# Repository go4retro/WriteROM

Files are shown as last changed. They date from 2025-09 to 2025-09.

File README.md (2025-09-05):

# WriteROM

WriteROM accomplishes the impossible, allowing one to write a ROM in place while installed in a circuit without a write line. No flying leads or pigtails are required. WriteROM allows writing to the FLASH using only read accesses.

In normal operation, WriteROM works just like a normal 28 pin JEDEC ROM. However, once a "knock" sequence of reads are performed on the device, the device enters into a programming mode, where address bits 7-0 are interpreted as the data, and bits 11-8 are considered the "operation". The following operations are supported:

| 10:8 | Description |
| ---- | --- |
| 0 | set low byte of address |
| 1 | set middle byte of address |
| 2 | set high byte of address |
| 6 | read from stored address |
| 7 | write to address |

As expected, programming times will be increased due to the additional level of abstraction, but such a device can be cleanly inserted into any memory map, even those not allowing writes to a specific range of memory.

Currently, the design includes a 4Mbit (512kB) FLASH ROM, though the design can be extended to larger sizes if desired.

## License

Copyright (C) 2025 RETRO Innovations

These files are free designs; you can redistribute them and/or modify
them under the terms of the Creative Commons Attribution-ShareAlike 
4.0 International License.

You should have received a copy of the license along with this
work. If not, see http://creativecommons.org/licenses/by-sa/4.0/.

These files are distributed in the hope that they will be useful,
but WITHOUT ANY WARRANTY; without even the implied warranty of
MERCHANTABILITY or FITNESS FOR A PARTICULAR PURPOSE. See the
license for more details.

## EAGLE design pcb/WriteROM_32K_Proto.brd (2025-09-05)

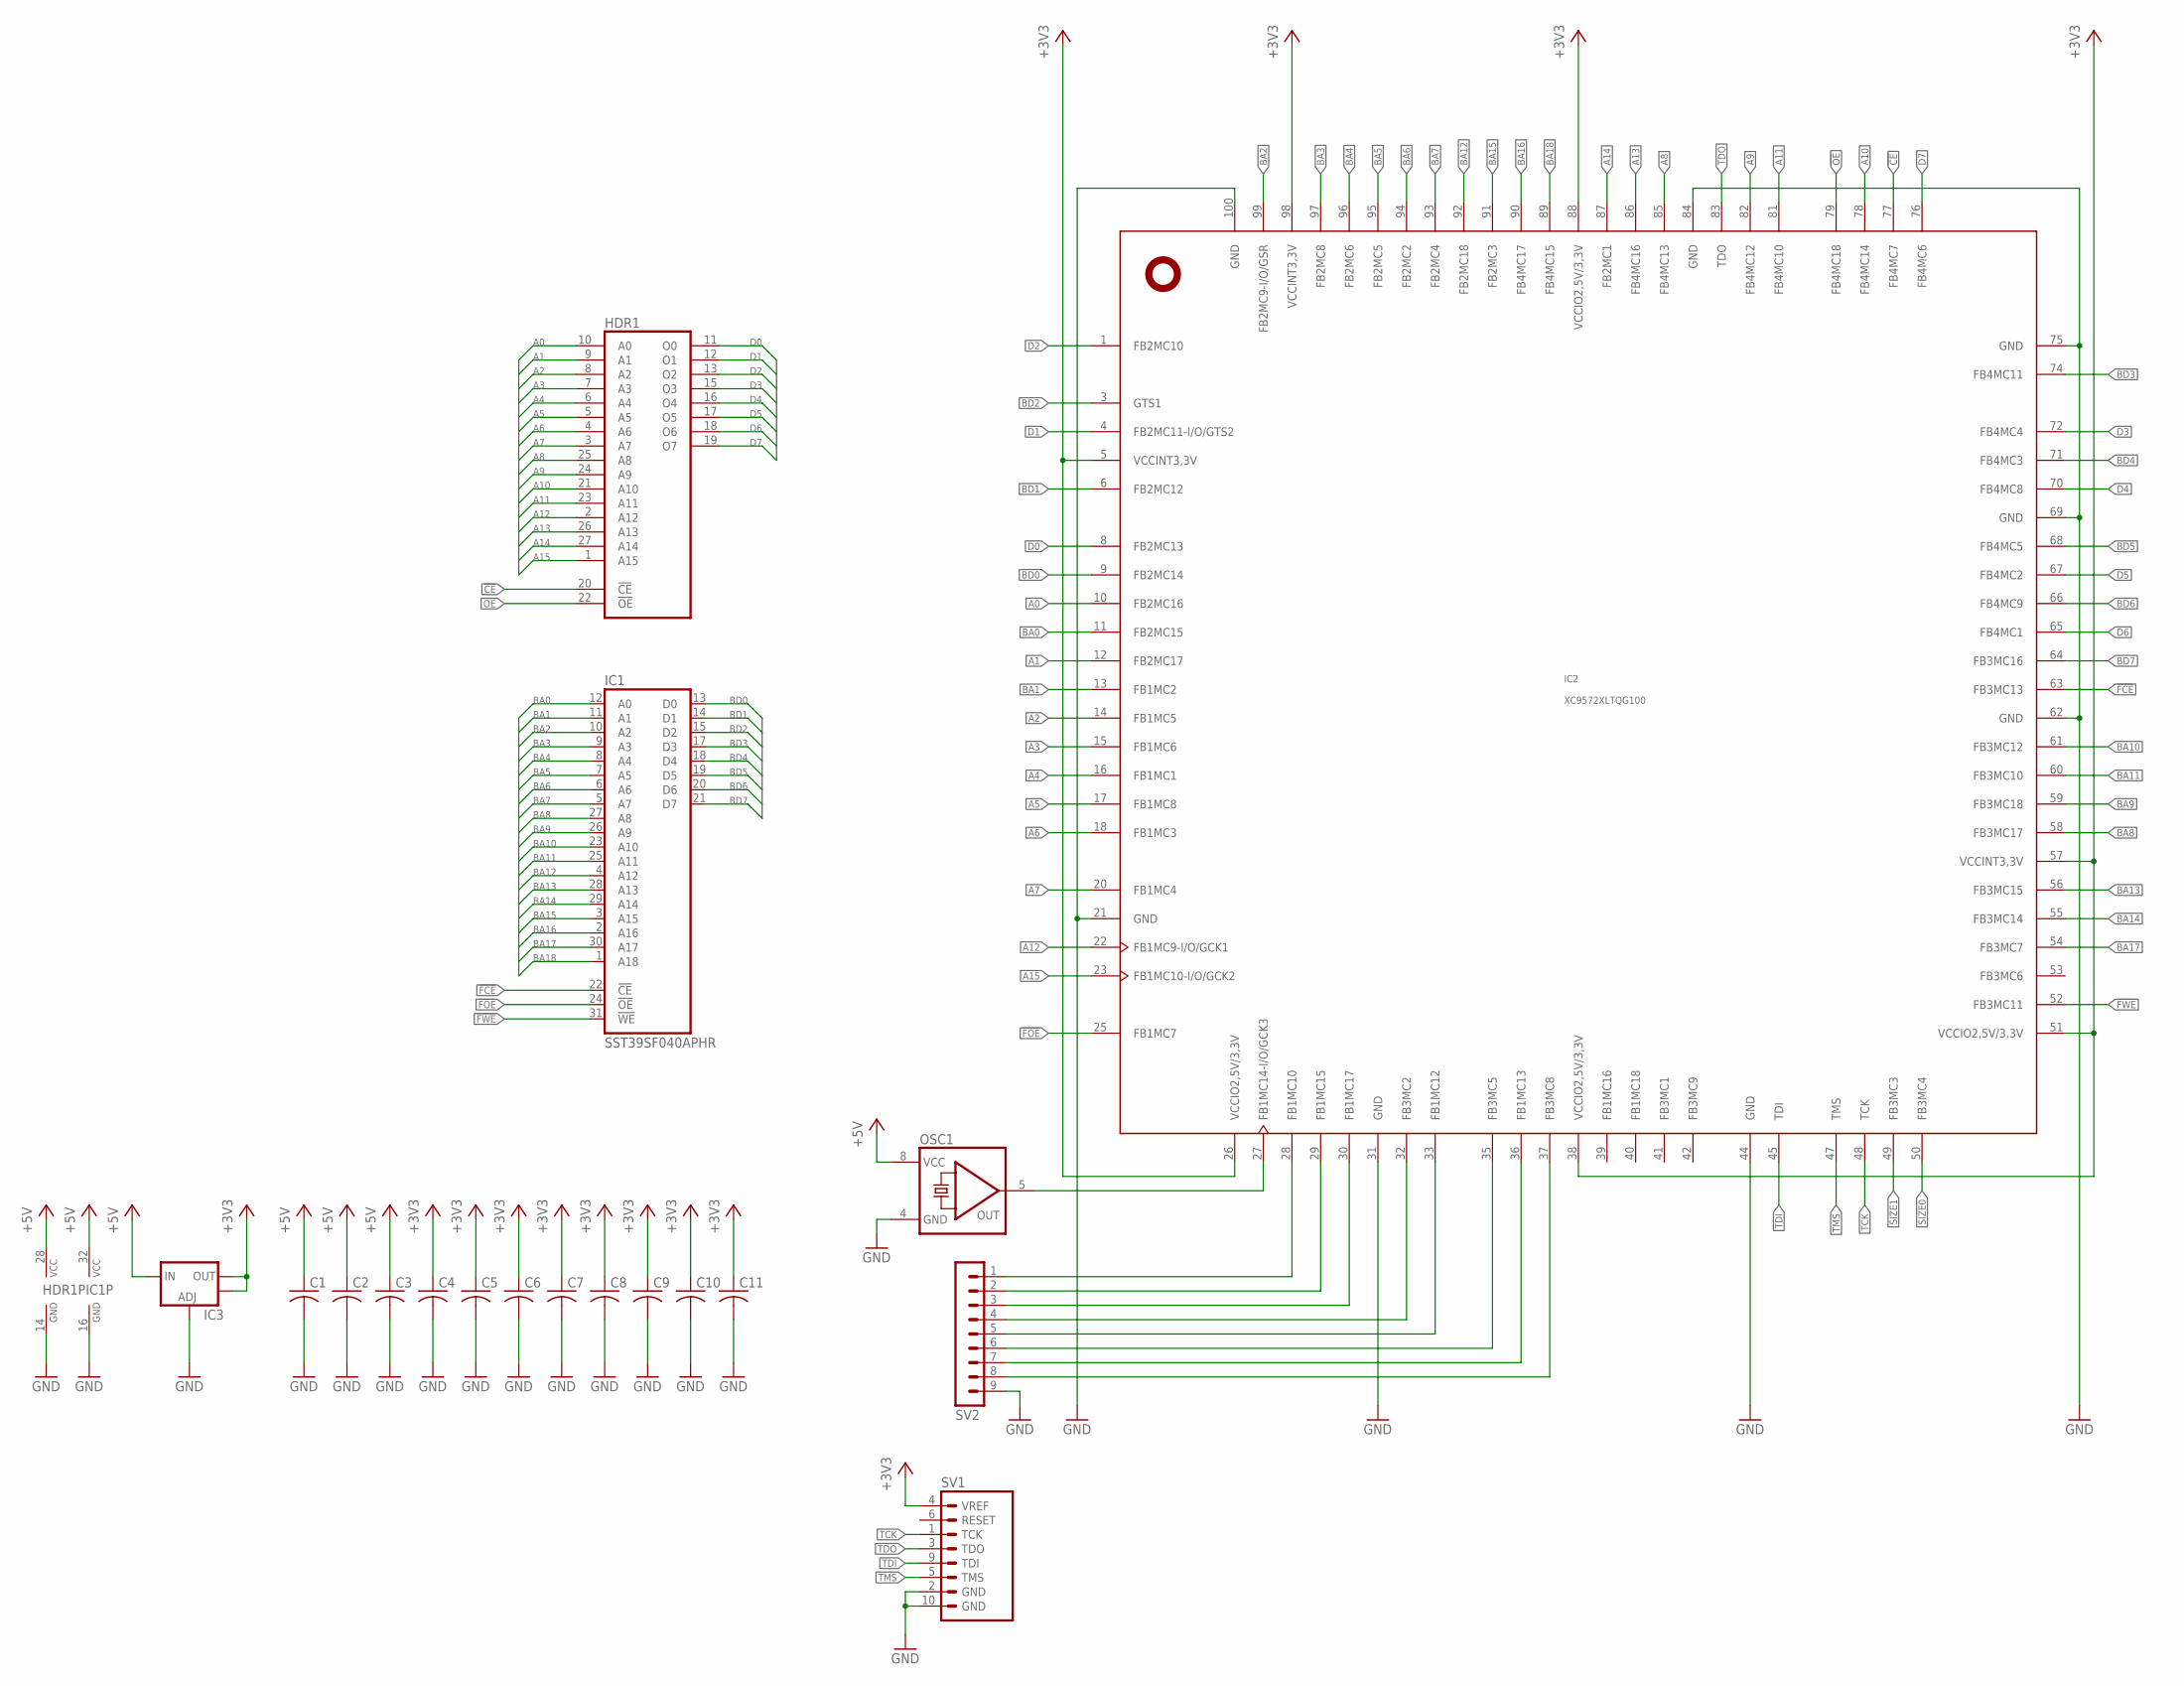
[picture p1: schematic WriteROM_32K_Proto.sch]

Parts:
C1, C4: C-USC0805; C0805
C2, C3, C5, C6, C7, C8, C9, C10, C11: C-USC0402; C0402
HDR1: 27512; DIL28
IC1: SST39SF040APHR; DIL32-RP
IC2: XC9572XLTQG100; TQFP100
IC3: V_REG_LM1117SOT223; SOT223
OSC1: QG5460; DIL08S
SV1: JTAG
SV2: MA09-1

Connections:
!CE: HDR1.20 (!CE), IC2.77 (FB4MC7)
!FCE: IC1.22 (!CE), IC2.63 (FB3MC13)
!FOE: IC1.24 (!OE), IC2.25 (FB1MC7)
!FWE: IC1.31 (!WE), IC2.52 (FB3MC11)
!OE: HDR1.22 (!OE), IC2.79 (FB4MC18)
+3V3: C4.1, C5.1, C6.1, C7.1, C8.1, C9.1, C10.1, C11.1, IC2.5 (VCCINT3,3V), IC2.26 (VCCIO2,5V/3,3V), IC2.38 (VCCIO2,5V/3,3V), IC2.51 (VCCIO2,5V/3,3V), IC2.57 (VCCINT3,3V), IC2.88 (VCCIO2,5V/3,3V), IC2.98 (VCCINT3,3V), IC3.2 (OUT), IC3.4 (OUT), SV1.4 (VREF)
+5V: C1.1, C2.1, C3.1, HDR1.28 (VCC), IC1.32 (VCC), IC3.3 (IN), OSC1.8 (VCC)
A0: HDR1.10 (A0), IC2.10 (FB2MC16)
A1: HDR1.9 (A1), IC2.12 (FB2MC17)
A2: HDR1.8 (A2), IC2.14 (FB1MC5)
A3: HDR1.7 (A3), IC2.15 (FB1MC6)
A4: HDR1.6 (A4), IC2.16 (FB1MC1)
A5: HDR1.5 (A5), IC2.17 (FB1MC8)
A6: HDR1.4 (A6), IC2.18 (FB1MC3)
A7: HDR1.3 (A7), IC2.20 (FB1MC4)
A8: HDR1.25 (A8), IC2.85 (FB4MC13)
A9: HDR1.24 (A9), IC2.82 (FB4MC12)
A10: HDR1.21 (A10), IC2.78 (FB4MC14)
A11: HDR1.23 (A11), IC2.81 (FB4MC10)
A12: HDR1.2 (A12), IC2.22 (FB1MC9-I/O/GCK1)
A13: HDR1.26 (A13), IC2.86 (FB4MC16)
A14: HDR1.27 (A14), IC2.87 (FB2MC1)
A15: HDR1.1 (A15), IC2.23 (FB1MC10-I/O/GCK2)
BA0: IC1.12 (A0), IC2.11 (FB2MC15)
BA1: IC1.11 (A1), IC2.13 (FB1MC2)
BA2: IC1.10 (A2), IC2.99 (FB2MC9-I/O/GSR)
BA3: IC1.9 (A3), IC2.97 (FB2MC8)
BA4: IC1.8 (A4), IC2.96 (FB2MC6)
BA5: IC1.7 (A5), IC2.95 (FB2MC5)
BA6: IC1.6 (A6), IC2.94 (FB2MC2)
BA7: IC1.5 (A7), IC2.93 (FB2MC4)
BA8: IC1.27 (A8), IC2.58 (FB3MC17)
BA9: IC1.26 (A9), IC2.59 (FB3MC18)
BA10: IC1.23 (A10), IC2.61 (FB3MC12)
BA11: IC1.25 (A11), IC2.60 (FB3MC10)
BA12: IC1.4 (A12), IC2.92 (FB2MC18)
BA13: IC1.28 (A13), IC2.56 (FB3MC15)
BA14: IC1.29 (A14), IC2.55 (FB3MC14)
BA15: IC1.3 (A15), IC2.91 (FB2MC3)
BA16: IC1.2 (A16), IC2.90 (FB4MC17)
BA17: IC1.30 (A17), IC2.54 (FB3MC7)
BA18: IC1.1 (A18), IC2.89 (FB4MC15)
BD0: IC1.13 (D0), IC2.9 (FB2MC14)
BD1: IC1.14 (D1), IC2.6 (FB2MC12)
BD2: IC1.15 (D2), IC2.3 (GTS1)
BD3: IC1.17 (D3), IC2.74 (FB4MC11)
BD4: IC1.18 (D4), IC2.71 (FB4MC3)
BD5: IC1.19 (D5), IC2.68 (FB4MC5)
BD6: IC1.20 (D6), IC2.66 (FB4MC9)
BD7: IC1.21 (D7), IC2.64 (FB3MC16)
D0: HDR1.11 (O0), IC2.8 (FB2MC13)
D1: HDR1.12 (O1), IC2.4 (FB2MC11-I/O/GTS2)
D2: HDR1.13 (O2), IC2.1 (FB2MC10)
D3: HDR1.15 (O3), IC2.72 (FB4MC4)
D4: HDR1.16 (O4), IC2.70 (FB4MC8)
D5: HDR1.17 (O5), IC2.67 (FB4MC2)
D6: HDR1.18 (O6), IC2.65 (FB4MC1)
D7: HDR1.19 (O7), IC2.76 (FB4MC6)
GND: C1.2, C2.2, C3.2, C4.2, C5.2, C6.2, C7.2, C8.2, C9.2, C10.2, C11.2, HDR1.14 (GND), IC1.16 (GND), IC2.21 (GND), IC2.31 (GND), IC2.44 (GND), IC2.62 (GND), IC2.69 (GND), IC2.75 (GND), IC2.84 (GND), IC2.100 (GND), IC3.1 (ADJ), OSC1.4 (GND), SV1.2 (GND), SV1.10 (GND), SV2.9
unnamed: IC2.27 (FB1MC14-I/O/GCK3), OSC1.5 (OUT)
SIZE0: IC2.50 (FB3MC4)
SIZE1: IC2.49 (FB3MC3)
TCK: IC2.48 (TCK), SV1.1 (TCK)
TDI: IC2.45 (TDI), SV1.9 (TDI)
TDO: IC2.83 (TDO), SV1.3 (TDO)
TES2: IC2.30 (FB1MC17), SV2.3
TEST0: IC2.28 (FB1MC10), SV2.1
TEST1: IC2.29 (FB1MC15), SV2.2
TEST3: IC2.32 (FB3MC2), SV2.4
TEST4: IC2.33 (FB1MC12), SV2.5
TEST5: IC2.35 (FB3MC5), SV2.6
TEST6: IC2.36 (FB1MC13), SV2.7
TEST7: IC2.37 (FB3MC8), SV2.8
TMS: IC2.47 (TMS), SV1.5 (TMS)

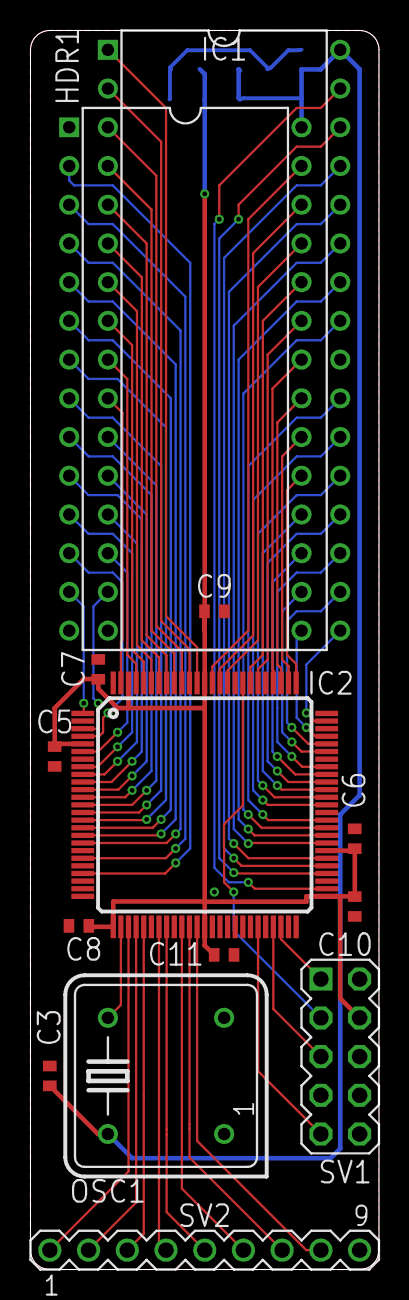
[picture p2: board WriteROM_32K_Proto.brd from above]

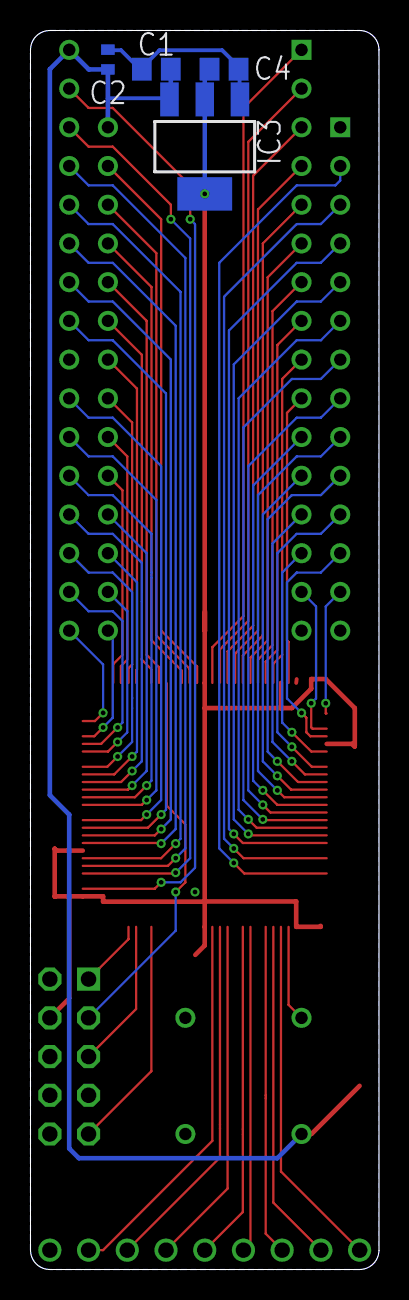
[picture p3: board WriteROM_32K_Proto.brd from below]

Board: 2 copper layers, 22.9 x 81.3 mm, 18 parts (4 on the bottom side), 72 nets.

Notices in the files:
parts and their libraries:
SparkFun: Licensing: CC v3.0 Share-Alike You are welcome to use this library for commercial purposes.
